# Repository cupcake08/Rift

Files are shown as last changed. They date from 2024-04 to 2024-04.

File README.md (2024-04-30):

<div align="center">
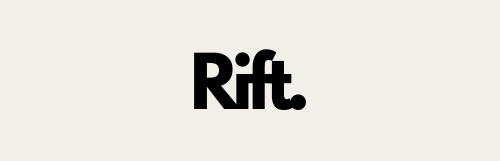
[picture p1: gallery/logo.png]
    
</div>

Rift is a 34-key wireless low profile split keyboard featuring Nice!View/OLED display ,Rotary Encoder (EC11/EC12) and optional trackpad support. It runs on [ZMK](https://zmk.dev/) firmware and is powered by the [Seeed Xiao nRF52840](https://www.seeedstudio.com/Seeed-XIAO-BLE-nRF52840-p-5201.html) board.

It also has a dedicated [Sort-Off](https://zmk.dev/docs/features/soft-off) switch.

## Keyboard Images
| Description | Photo |
| :--: | :--: |
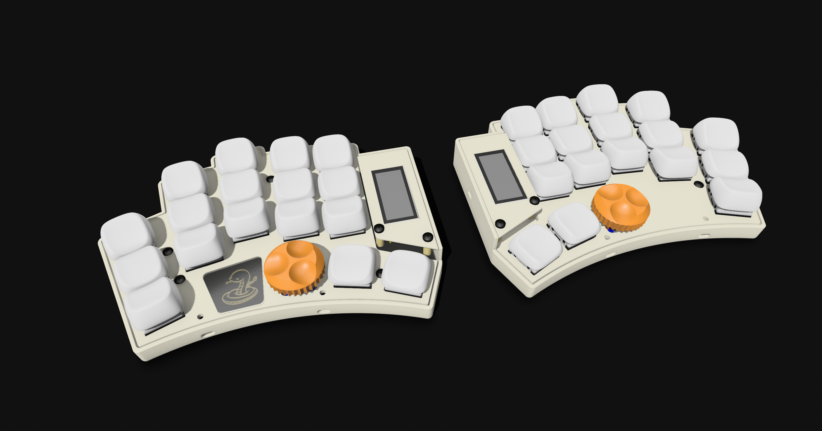
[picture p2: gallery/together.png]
| Left and Right half |  |
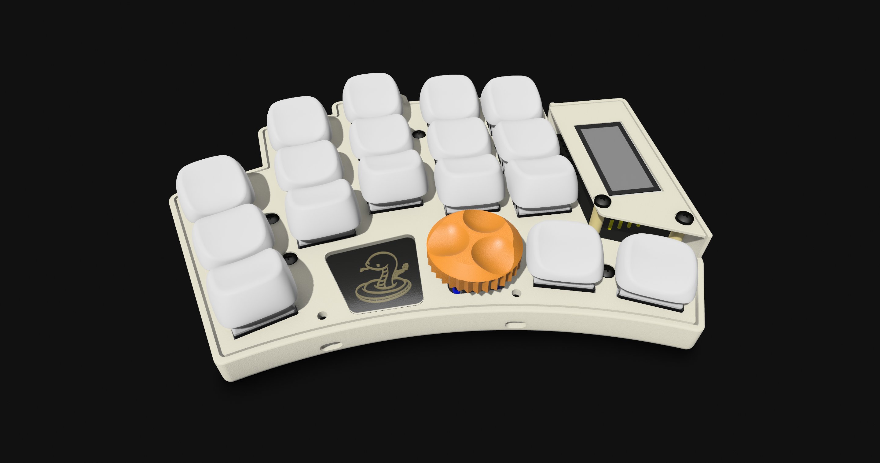
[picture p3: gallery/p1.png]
| With [KLP Lamé](https://github.com/braindefender/KLP-Lame-Keycaps/blob/master/README.md)  keycaps |  |
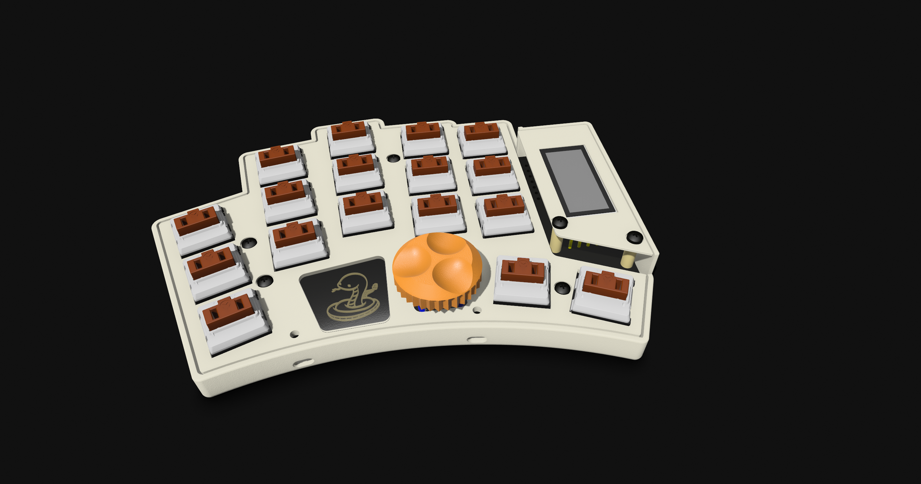
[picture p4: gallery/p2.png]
| With Kailh V1 LP switches |  |
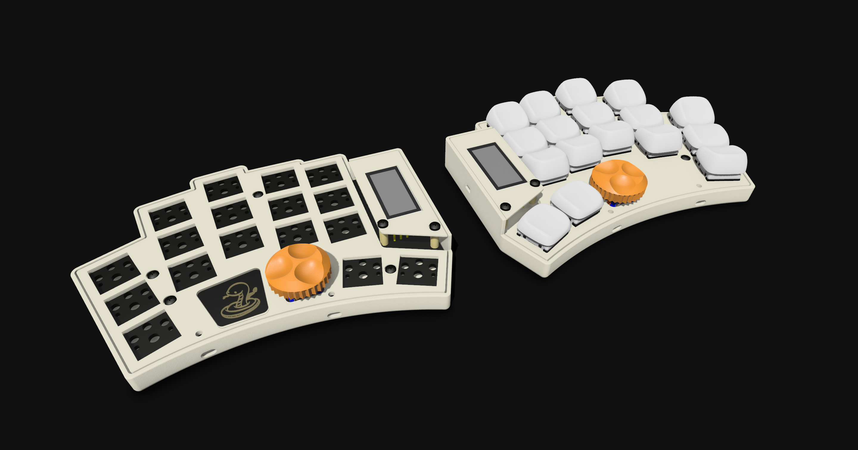
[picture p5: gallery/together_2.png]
| No keycaps and switches on Left half |  |

*These images are from cad
## PCB Images
| Description | Front | Back |
| :--: | :--: | :--: |
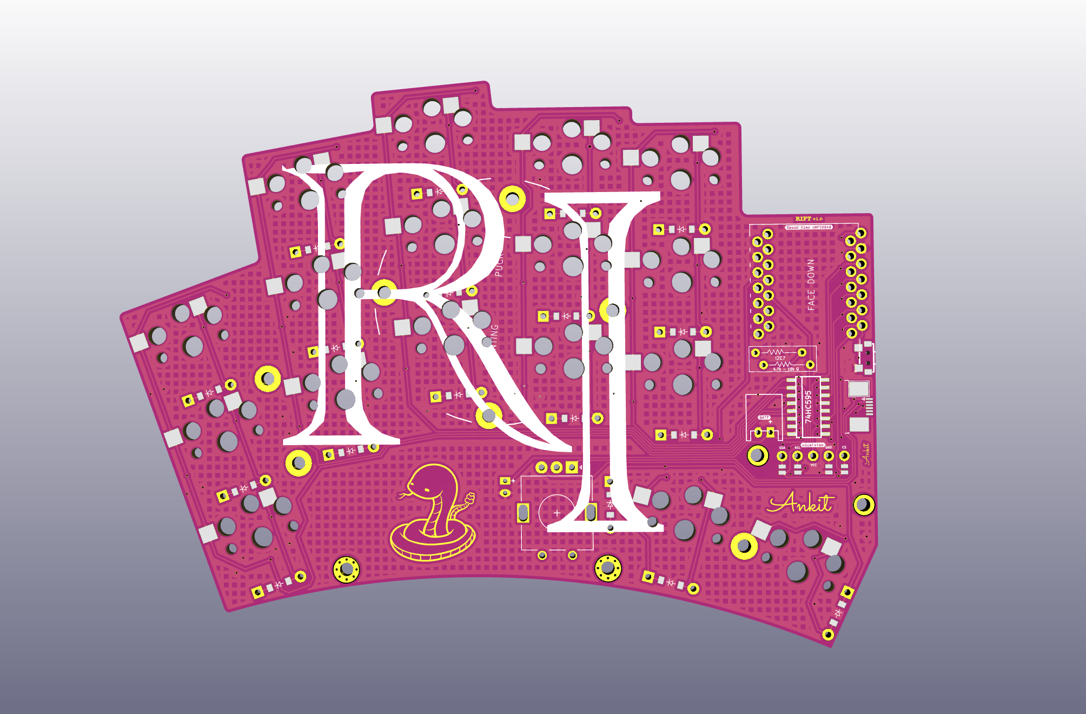
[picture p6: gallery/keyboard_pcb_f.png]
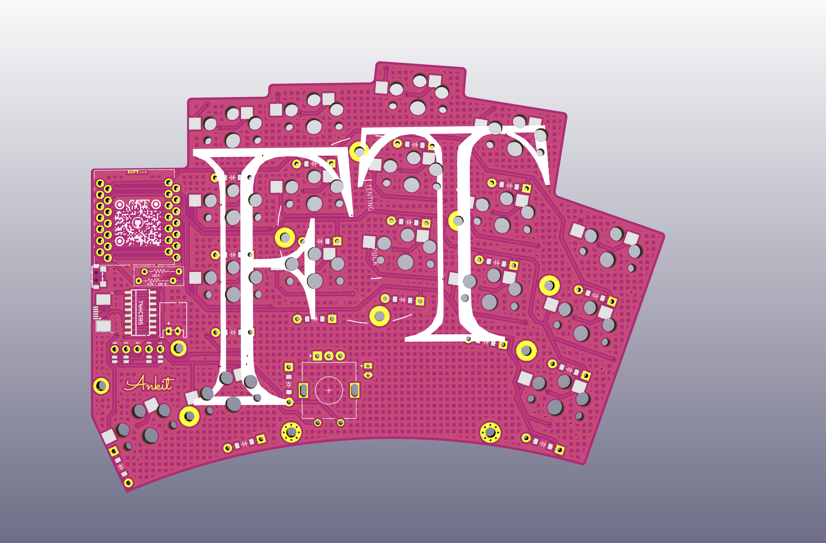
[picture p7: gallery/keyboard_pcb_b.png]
| Keyboard PCB Front |  |  |
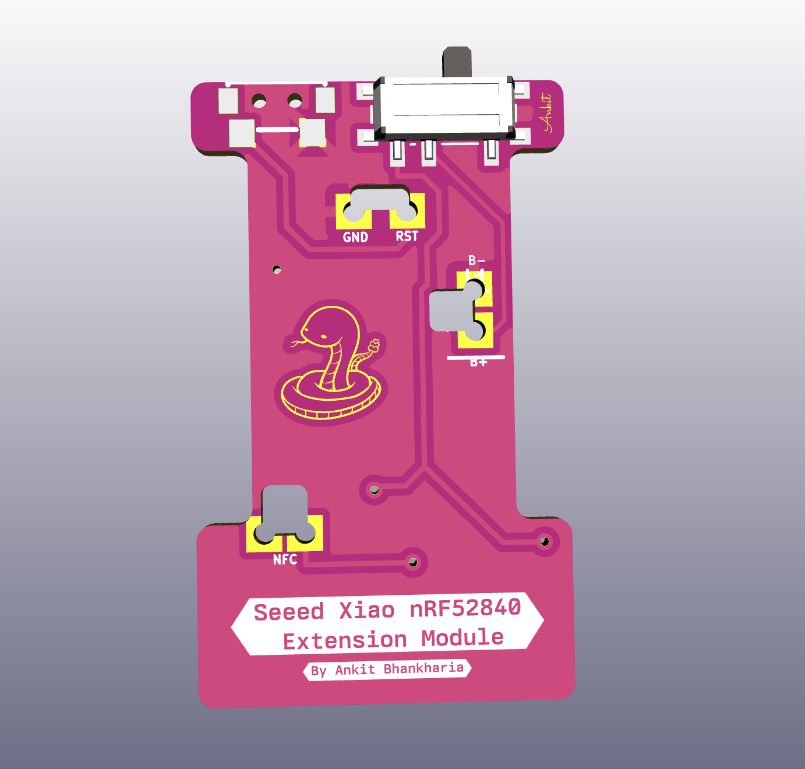
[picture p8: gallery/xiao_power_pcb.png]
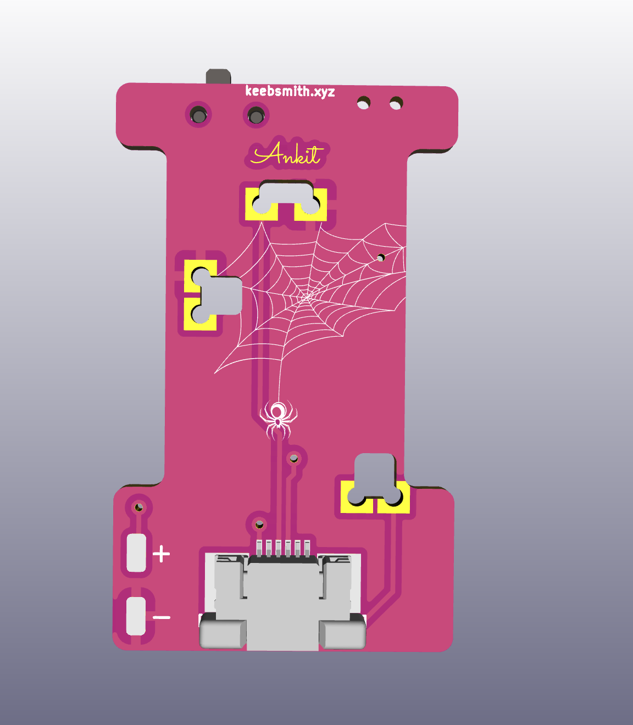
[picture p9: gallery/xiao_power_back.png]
| Xiao Extension |  |  |

### Inspiration
- [Ferris(Sweep)](https://github.com/davidphilipbarr/Sweep)

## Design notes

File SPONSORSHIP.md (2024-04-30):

Hello,

I hope this message finds you well. I am reaching out to inquire about the possibility of receiving sponsorship for my project, Rift—a complete open-source keyboard designed to empower enthusiasts to build their own customizable keyboards.

## Introduction
My name is Ankit Bhankharia, and I am a final-year engineering student from India. While my background is primarily in software, I have recently delved into hardware projects with great enthusiasm. Over the past year, I have embarked on a journey exploring mechanical keyboards, which has led me to develop a passion for creating innovative input devices.

# Project Description
Rift is a 34-key wireless low-profile split keyboard equipped with a Nice!View/OLED display, Rotary Encoder (EC11/EC12), and optional trackpad support. It operates on the ZMK firmware and is powered by the Seeed Xiao nRF52840 board.

The inspiration for Rift stemmed from my desire to create an affordable, portable keyboard solution reminiscent of the beloved Sweep keyboard design. The Seeed Xiao board stood out as an ideal candidate due to its affordability and wireless capabilities. However, the limited I/O pins posed a challenge in implementing additional hardware features such as displays, rotary encoders, and pointing devices.

To overcome this limitation, I devised a solution involving the use of a Shift register to expand the available I/O pins. Additionally, I addressed the issue of inaccessible NFC pins by designing a supplementary PCB that interfaces with the Seeed Xiao board, allowing for hot-swappability and easy access to essential functions.

Furthermore, I meticulously designed a low-profile case for the keyboard, optimizing space utilization and integrating a 250mAh battery for extended usage. After thorough testing on a breadboard, the keyboard has proven to meet expectations, boasting a battery life of up to three weeks on a single charge.

You can explore the project files and view generated images on my GitHub repository at [Rift Github Repo](https://github.com/cupcake08/Rift).

# Final Request

With all components functioning as intended, I am seeking sponsorship specifically for PCB fabrication services to bring Rift to fruition. In return for your support, I am committed to showcasing Seeed Studio's contribution prominently across various platforms, from my GitHub repository to blog posts on platforms like Hackster.

Your consideration of my project is greatly appreciated. Thank you for taking the time to learn about Rift and its potential impact on the open-source hardware community.

Warm regards,

Ankit Bhankharia

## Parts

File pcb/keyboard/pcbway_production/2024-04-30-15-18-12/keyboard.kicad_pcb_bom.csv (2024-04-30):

designator | quantity | value | pack | mpn | mount_type
, | 2 |  | TE_0-1734839-6_1x06-1MP_P0.5mm_Horizontal |  | tht
74HC595, 74HC595 | 2 | VAL** | SOIC16 |  | smt
D1, D10, D11, D12, D13, D14, D15, D16, D17, D18, D2, D3, D4, D5, D6, D7, D8, D9 | 18 |  | ComboDiode |  | tht
JST1, JST1 | 2 |  | JST_XH_S2B-XH-K_02x2.54mm_Angled |  | tht
Nice!View1 | 1 |  | niceview_headers |  | tht
ROT1 | 1 |  | rotary_encoder |  | tht
S1, S10, S11, S12, S13, S14, S15, S16, S17, S2, S3, S4, S5, S6, S7, S8, S9 | 17 |  | PG1350 |  | tht
U?, U? | 2 | Seeed Xiao | XiaoBle |  | tht
_1 | 1 | Tenting Puck | Tenting Puck |  | tht
_2, _3, _4, _5 | 4 |  | MountingHole_2.2mm_M2_Pad_Via |  | tht
kibuzzard-66181547 | 1 | G*** | kibuzzard-66181547 |  | tht
kibuzzard-66181572 | 1 | G*** | kibuzzard-66181572 |  | tht
kibuzzard-6618164F | 1 | G*** | kibuzzard-6618164F |  | tht

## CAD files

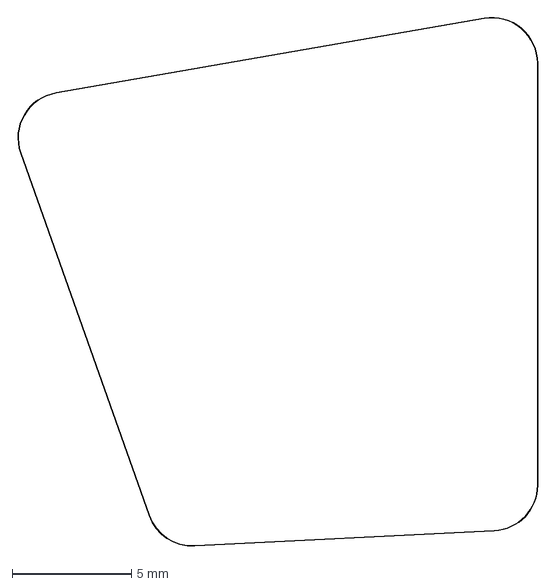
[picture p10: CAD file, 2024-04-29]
case/v1/Acrylic.dxf
21.9 x 22.3 mm

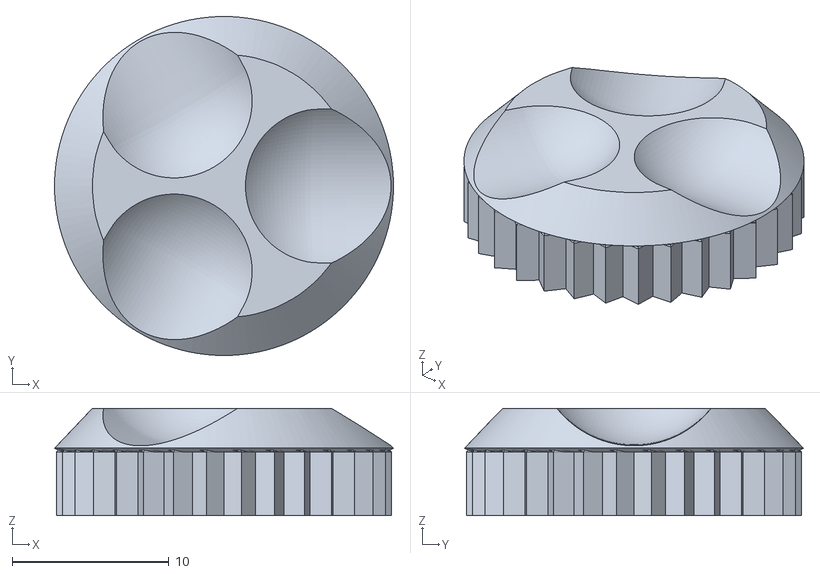
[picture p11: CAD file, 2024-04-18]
knob/KLOTZ EC12 Knob v02 04.stl
21.6 x 21.6 x 6.86

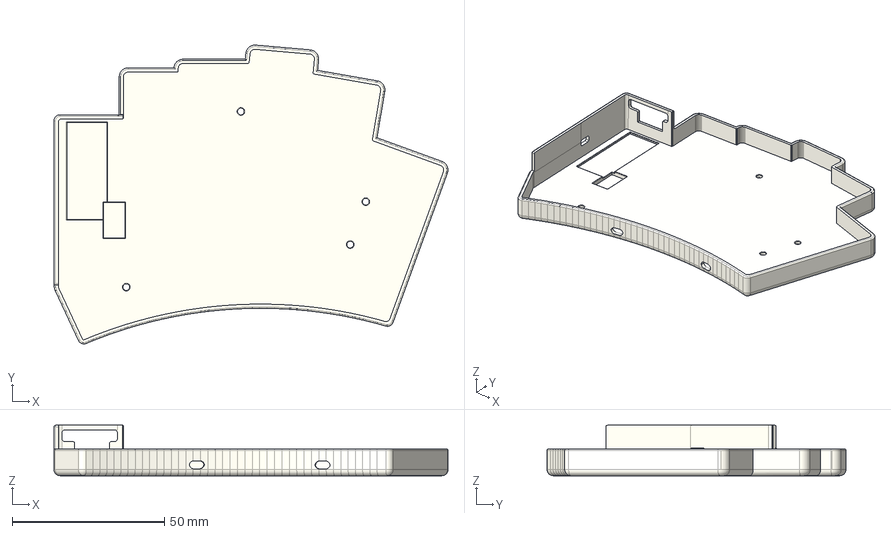
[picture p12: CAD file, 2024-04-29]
case/v1/case_right.step
129.5 x 98.2 x 16.6 mm
standoffs
right
left
M2 x 3 Screw head.SLDPRT (5)
M2 x 3 Screw head.SLDPRT (4)
M2 x 3 Screw head.SLDPRT (3)
M2 x 3 Screw head.SLDPRT (2)
M2 x 3 Screw head.SLDPRT (1)
M2 x 3 Screw head.SLDPRT

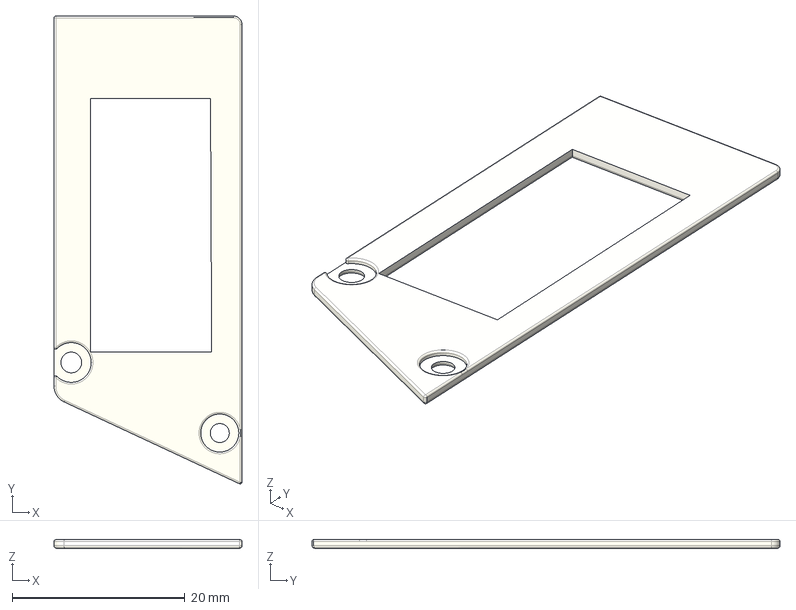
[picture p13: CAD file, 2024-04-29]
case/v1/display_cover_left.step
21.7 x 54.1 x 1.00 mm
standoffs
right
left
M2 x 3 Screw head.SLDPRT (5)
M2 x 3 Screw head.SLDPRT (4)
M2 x 3 Screw head.SLDPRT (3)
M2 x 3 Screw head.SLDPRT (2)
M2 x 3 Screw head.SLDPRT (1)
M2 x 3 Screw head.SLDPRT

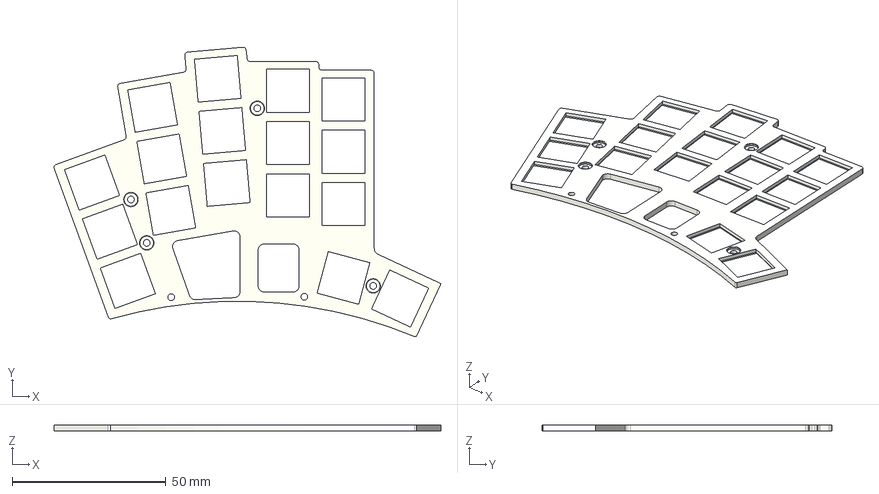
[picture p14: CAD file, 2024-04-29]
case/v1/switchplate_left.step
125.8 x 94.1 x 2.00 mm
standoffs
right
left
M2 x 3 Screw head.SLDPRT (5)
M2 x 3 Screw head.SLDPRT (4)
M2 x 3 Screw head.SLDPRT (3)
M2 x 3 Screw head.SLDPRT (2)
M2 x 3 Screw head.SLDPRT (1)
M2 x 3 Screw head.SLDPRT

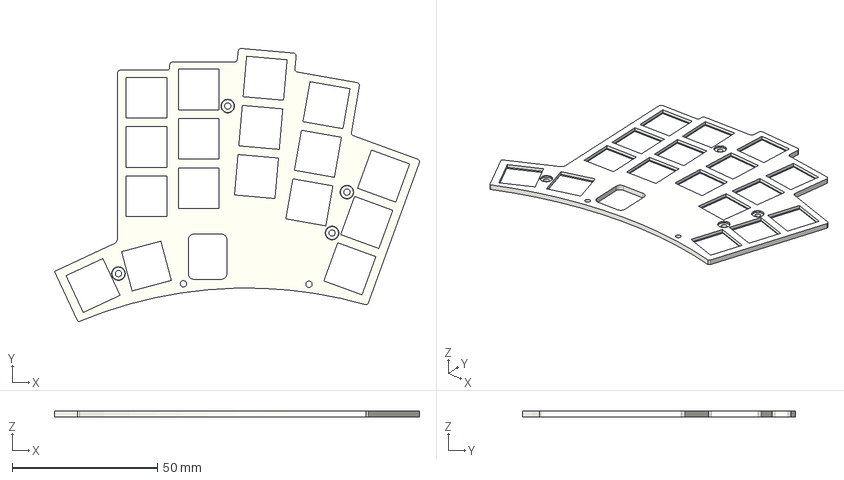
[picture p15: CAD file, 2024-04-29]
case/v1/switchplate_right.step
125.8 x 94.1 x 2.00 mm
standoffs
right
left
M2 x 3 Screw head.SLDPRT (5)
M2 x 3 Screw head.SLDPRT (4)
M2 x 3 Screw head.SLDPRT (3)
M2 x 3 Screw head.SLDPRT (2)
M2 x 3 Screw head.SLDPRT (1)
M2 x 3 Screw head.SLDPRT

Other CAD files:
case/v1/display_cover_right.step
case/v1/case_left.step

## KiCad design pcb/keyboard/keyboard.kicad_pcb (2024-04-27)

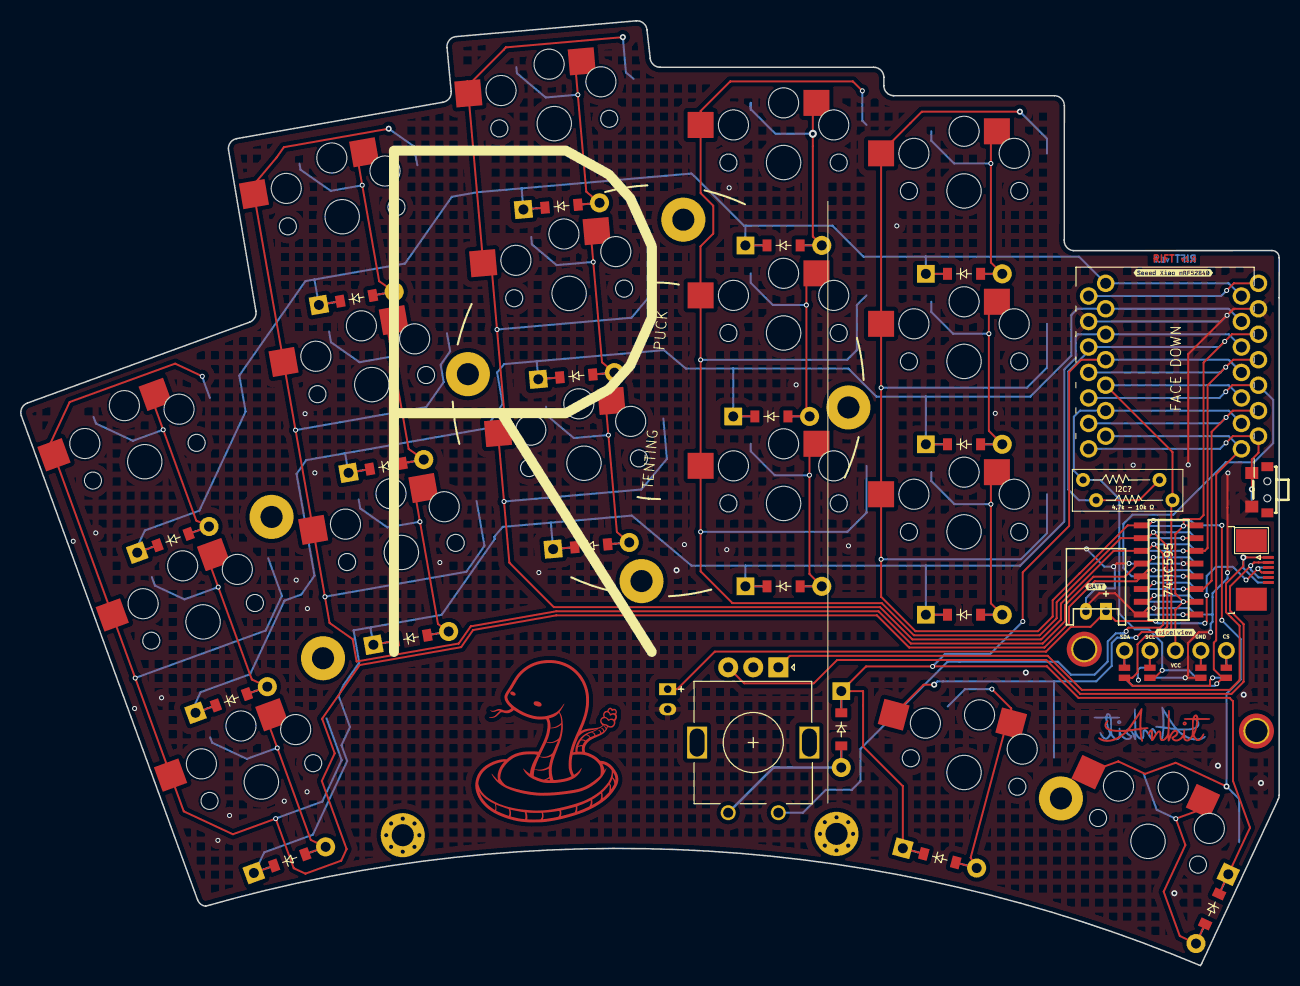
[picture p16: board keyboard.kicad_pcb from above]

Board: 2 copper layers, 125.5 x 94.2 mm, 51 parts (1 on the bottom side), 44 nets.

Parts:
74HC595, 74HC595#2: VAL**; SOIC16
D1, D2, D3, D4, D5, D6, D7, D8, D9, D10, D11, D12, D13, D14, D15, D16, D17, D18: ComboDiode
JST1, JST1#2: JST_XH_S2B-XH-K_02x2.54mm_Angled
Nice!View1: niceview_headers
ROT1: rotary_encoder
S1, S2, S3, S4, S5, S6, S7, S8, S9, S10, S11, S12, S13, S14, S15, S16, S17: PG1350
U?: Seeed Xiao; XiaoBle
U?#2: Seeed Xiao; XiaoBle
_1: Tenting Puck
_2, _3, _4, _5: MountingHole_2.2mm_M2_Pad_Via
kibuzzard-6618164F: G***; kibuzzard-6618164F
kibuzzard-66181547: G***; kibuzzard-66181547
kibuzzard-66181572: G***; kibuzzard-66181572

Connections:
BAT: JST1.1, JST1#2.1
ENC: D18.2, ROT1.2
GND: 74HC595.8, 74HC595.13, 74HC595#2.8, 74HC595#2.13, JST1.2, JST1#2.2, Nice!View1.2, ROT1.C, U?.13, U?#2.13
P0: D3.1, D6.1, D9.1, D12.1, D15.1, U?.1, U?#2.1
P1: D2.1, D5.1, D8.1, D11.1, D14.1, U?.2, U?#2.2
P2: D1.1, D4.1, D7.1, D10.1, D13.1, U?.3, U?#2.3
P3: D16.1, D17.1, D18.1, U?.4, U?#2.4
P4: Nice!View1.2, U?.5, U?#2.5
P5: Nice!View1.2, U?.6, U?#2.6
P6: Nice!View1.2, U?.7, U?#2.7
P7: U?.8, U?#2.8
P8: 74HC595.11, 74HC595#2.11, U?.9, U?#2.9
P9: 74HC595.12, 74HC595#2.12, U?.10, U?#2.10
P10: 74HC595.14, 74HC595#2.14, U?.11, U?#2.11
Q0: 74HC595.15, 74HC595#2.15
Q1: 74HC595.1, 74HC595#2.1, S13.2, S14.2, S15.2, S17.2
Q2: 74HC595.2, 74HC595#2.2, S10.2, S11.2, S12.2, S16.2
Q3: 74HC595.3, 74HC595#2.3, ROT1.1, S7.2, S8.2, S9.2
Q4: 74HC595.4, 74HC595#2.4, S4.2, S5.2, S6.2
Q5: 74HC595.5, 74HC595#2.5, S1.2, S2.2, S3.2
Q6: 74HC595.6, 74HC595#2.6
Q7: 74HC595.7, 74HC595#2.7
Q7S: 74HC595.9, 74HC595#2.9
SCL: Nice!View1.1, Nice!View1.3
SDA: Nice!View1.1, Nice!View1.4
VCC: 74HC595.10, 74HC595.16, 74HC595#2.10, 74HC595#2.16, Nice!View1.2, U?.12, U?#2.12
VCC_5V: U?.14, U?#2.14
index_bottom: D10.2, S10.1
index_home: D11.2, S11.1
index_top: D12.2, S12.1
inner_bottom: D13.2, S13.1
inner_cluster: D16.2, S16.1
inner_home: D14.2, S14.1
inner_top: D15.2, S15.1
middle_bottom: D7.2, S7.1
middle_home: D8.2, S8.1
middle_top: D9.2, S9.1
outer_cluster: D17.2, S17.1
pinky_bottom: D1.2, S1.1
pinky_home: D2.2, S2.1
pinky_top: D3.2, S3.1
ring_bottom: D4.2, S4.1
ring_home: D5.2, S5.1
ring_top: D6.2, S6.1

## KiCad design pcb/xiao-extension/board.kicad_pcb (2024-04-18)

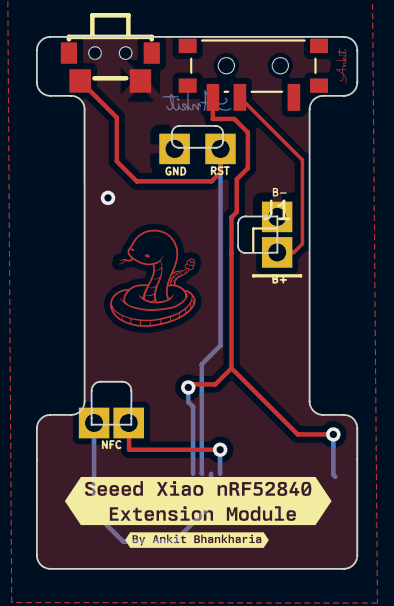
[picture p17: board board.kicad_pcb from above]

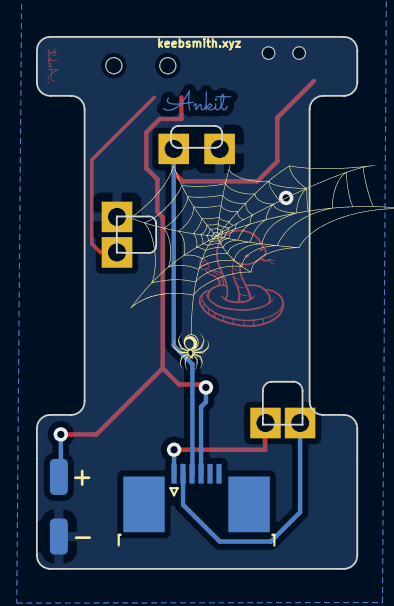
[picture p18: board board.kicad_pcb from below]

Board: 2 copper layers, 17.8 x 29.6 mm, 13 parts (3 on the bottom side), 6 nets.

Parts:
J1, J2, J3, J4: Conn_01x01_Pin; PinHeader_1x01_P2.54mm_Vertical
J5, J6: Conn_01x01_Pin; SolderWirePad_1x01_SMD_1x2mm
J8, J9: Conn_01x01; PinHeader_1x01_P2.54mm_Vertical
J10: Conn_01x05; TE_0-1734839-6_1x06-1MP_P0.5mm_Horizontal
SW2: SW_SPDT; SW_SPDT_PCM12
U2: TS24CA; TC24CA
kibuzzard-661B5F0D: G***; kibuzzard-661B5F0D
kibuzzard-661B5F47: G***; kibuzzard-661B5F47

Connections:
BAT_+: J1.1, SW2.2 (B)
BAT_++: J5.1, J10.4, SW2.3 (C)
ENC_A: J8.1, J10.1
ENC_B: J9.1, J10.2
GND: J2.1, J4.1, J6.1, U2.3
RST: J3.1, J10.3, U2.4

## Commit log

2024-04-12 pcb setup
    [board.kicad_pcb, bom.csv, designators.csv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]
2024-04-12 added gerbers
    [board.kicad_pcb, bom.csv, designators.csv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]
2024-04-18 directory structure fix
    [KLOTZ EC12 Knob v02 04.stl, board.kicad_pcb, bom.csv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]
2024-04-25 imp: pcb design change
    [keyboard.kicad_pcb]
2024-04-25 add: pcb images
2024-04-27 add: i2c resistor pull resistor
    [keyboard.kicad_pcb]
2024-04-27 add: i2c pull-up resistors and name on silkscreen
    [keyboard.kicad_pcb]
2024-04-29 add: 3D models
    [case_left.step, case_right.step, display_cover_left.step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]
2024-04-29 add: 3DP case
    [Acrylic.dxf]
2024-04-30 add: sponsorship.md
    [keyboard.kicad_pcb_bom.csv, keyboard.kicad_pcb_positions.csv]
